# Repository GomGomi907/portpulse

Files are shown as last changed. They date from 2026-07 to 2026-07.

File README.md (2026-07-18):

# PortPulse

## 무엇인가

PortPulse는 PC와 USB 장치(DUT) 사이에 연결하는 USB 2.0 재연결 동글입니다.

PC와 제어 MCU의 연결은 유지한 채, 외부 DUT의 VBUS와 D+/D−를 소프트웨어로
차단하고 복구합니다. 따라서 USB 장치를 실제로 뽑았다가 다시 연결하는 동작을
자동화 테스트에서 재현할 수 있습니다.

## 사용 방법

1. PortPulse의 USB-C upstream 포트를 PC에 연결합니다.
2. DUT를 PortPulse의 USB-A downstream 포트에 연결합니다.
3. 장치 관리자에서 PortPulse의 COM 포트 번호를 확인합니다.
4. 네이티브 `portpulse` 프로그램으로 명령을 보냅니다.

```text
portpulse --port COM12 status
portpulse --port COM12 on
portpulse --port COM12 off
portpulse --port COM12 --delay-ms 2000 cycle
```

주요 명령:

- `on`: DUT 연결
- `off`: DUT 차단
- `cycle`: DUT를 차단한 뒤 지정한 시간 후 다시 연결
- `status`: 현재 상태 확인
- `fault`: 전원 스위치 Fault 상태 확인
- `version`: 펌웨어 버전 확인

현재 Rev.C.1은 DUT 1포트를 지원합니다. 여러 PortPulse를 연결하는 경우에는
각 장치의 COM 포트를 지정해서 사용합니다.

하드웨어·펌웨어·호스트 프로그램은 MIT License로 배포합니다. 제3자 구성요소는
각 구성요소의 고지 파일을 따릅니다.

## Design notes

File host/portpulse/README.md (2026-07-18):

# PortPulse native host

Small native C host for the PortPulse CH552 CDC interface. It uses the OS
serial driver already provided by Windows or Linux; no Python runtime is
required.

Build with CMake:

```sh
cmake -S . -B build
cmake --build build --config Release
```

Examples:

```text
portpulse --port COM12 status
portpulse --port COM12 on
portpulse --port COM12 off
portpulse --port COM12 --delay-ms 2000 cycle
```

The current Rev.C.1 firmware exposes one logical target port. Device
auto-discovery and `--device <serial>` selection are planned for the next
host iteration; explicit port selection is intentional until multi-device
enumeration is added.

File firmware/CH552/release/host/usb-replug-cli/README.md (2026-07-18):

# USB Replug Dongle Rev.C.1 Host CLI

CDC serial CLI for CH552 firmware `0.2.1-revc1`.

## Usage

Run from this directory:

```powershell
py -m usb_replug ports
py -m usb_replug status
py -m usb_replug off
py -m usb_replug on
py -m usb_replug cycle --delay-ms 2000
py -m usb_replug --port COM12 status
py -m usb_replug --port COM12 off
py -m usb_replug --port COM12 on
py -m usb_replug --port COM12 cycle --delay-ms 2000
py -m usb_replug --port COM12 fault
py -m usb_replug --port COM12 version
```

When `--port` is omitted, the CLI auto-discovers a pyserial port matching USB
VID/PID `0x1a86:0x5722`. Override the IDs with decimal or `0x` hex values, and
use `--serial` to require a serial-number substring:

```powershell
py -m usb_replug --vid 0x1A86 --pid 0x5722 ports
py -m usb_replug --serial ABC123 status
```

Auto-discovery fails clearly if no port or more than one port matches. Passing
`--port` always takes precedence over auto-discovery.

The CLI requires `pyserial` when talking to real hardware:

```powershell
py -m pip install pyserial
```

The firmware command protocol uses plain ASCII lines and returns one response line per command.

The CLI rejects `cycle --delay-ms` values outside the firmware
`0.2.1-revc1` range of 100 to 30000 ms before opening the serial port.
For every `cycle`, the serial timeout is raised automatically to at least the
effective delay plus 2 seconds; a cycle without `--delay-ms` uses the firmware
default of 2000 ms. Device `ERR ...` responses are written to stderr and return
exit status 1.

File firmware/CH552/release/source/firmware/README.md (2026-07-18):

# USB Replug Dongle Rev.C.1 — CH552 firmware

This is the production-board firmware target for the cost-optimized Rev.C.1
hardware. The earlier `firmware/usb_replug_fw` directory is the superseded
STM32F042 Rev.C scaffold and must not be flashed to Rev.C.1.

## Implemented behavior

- CH552 USB Full-Speed CDC ACM command interface
- Windows inbox `usbser.sys` compatible device-class descriptors
- Stable chip-ID-derived serial number: `RVC1-XXXXXXXXXX`
- Reset-safe DUT state: VBUS off and D+/D- disconnected
- Active-low Rev.C.1 GPIO mapping
- Fault interlock and automatic safe-off after a fault on power-up
- Commands:
  - `on` / `on 1`
  - `off` / `off 1`
  - `cycle [100..30000]`
  - `cycle 1 [100..30000]`
  - `status [1]`
  - `fault`
  - `version`
  - `help`

The ON sequence connects D+/D- first, waits 20 ms, enables DUT VBUS, waits
100 ms, then checks the over-current fault again. OFF disconnects D+/D-
before removing VBUS.

## Pin contract

| CH552 pin | Net | Logical behavior |
|---|---|---|
| P1.0 / pin 7 | `TARGET_PWR_EN_N` | Low = DUT VBUS on |
| P1.1 / pin 8 | `TARGET_DATA_CMD` | Low = connected; open-drain release = disconnected |
| P3.1 / pin 9 | NC | High-impedance after startup; no CH334U reset connection |
| P3.0 / pin 10 | `TARGET_FAULT_N` | 5 V-domain input; low = over-current fault |
| P3.6 / pin 14 | `MCU_USB_DP` | USB D+ |
| P3.7 / pin 15 | `MCU_USB_DM` | USB D- |

CH334U `RESET#/CDP` is deliberately not driven by the MCU. The hub uses its
internal POR and pull-up as WCH recommends; TP8 remains available to assert a
manual active-low reset during bring-up.

Rev.C.1 powers CH552 `VCC` from `VBUS_IN` (nominal 5 V). That is a mandatory
precondition for the selected 24 MHz system clock; the build fails if
`CH552_VCC_MV` is configured below 4400.

## Build and tests

Prerequisites:

- SDCC 4.6.0 with MCS-51 support
- Python 3
- GCC for portable host-side C tests

Run:

```powershell
cd D:\oh_my_usb\firmware\usb_replug_ch552
py build.py all
```

Outputs:

```text
build/sdcc/usb_replug_ch552.bin
build/sdcc/usb_replug_ch552.hex
build/sdcc/usb_replug_ch552.ihx
build/sdcc/usb_replug_ch552.map
build/sdcc/usb_replug_ch552.mem
```

The build enforces the CH552 application limits: code below `0x3800` because
the upper 2 KiB is the factory bootloader, and application XRAM from `0x0100`
through `0x03ff`. USB DMA buffers occupy the hardware-sized fixed regions
`0x0000..0x003f` (EP0), `0x0040..0x007f` (EP1 TX), and
`0x0080..0x00ff` (EP2 RX/TX).

The build script also works around an SDCC 4.6.0 Windows packaging issue where
the private preprocessor backend can otherwise be confused with MinGW's
`cc1.exe`.

## USB identifiers

The default engineering VID/PID is `1A86:5722`, matching the host CLI defaults.
It is not an ownership grant. Before distribution, replace it at build time
with manufacturer-owned or licensed identifiers:

```powershell
# Add -DUSB_REPLUG_VID=... and -DUSB_REPLUG_PID=... to the SDCC flags.
```

## Programming

J3 exposes VBUS, GND, RST, P1.4, P1.6, and P1.7 for CH552 ISP/programming.
Program `build/sdcc/usb_replug_ch552.bin` with a CH55x-compatible WCH ISP tool.
Do not erase or overwrite the factory bootloader region at `0x3800..0x3fff`.

## Physical validation still required

Offline tests validate the command state machine, GPIO ordering contract,
descriptor structure, toolchain link, and memory limits. Final acceptance
requires assembled hardware for USB enumeration, voltage-level checks, fault
injection, and repeated DUT replug testing.

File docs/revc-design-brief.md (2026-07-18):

# USB Replug Dongle Rev.C — USB-stick-class redesign brief

Date: 2026-06-23

## Decision

Skip Rev.B and target Rev.C directly as a compact USB-stick-class product spin.

## Rev.C target

- Functional scope: keep Rev.A core function unchanged: PC sees a USB 2.0 hub, always-connected control MCU, and switched target USB port.
- Mechanical target: 55–62 mm length × 18–22 mm width.
- First layout envelope: 62 mm × 22 mm if retaining the current USB-A female footprint; shrink toward 55 mm × 20 mm after connector/MCU package selection.
- PCB: 4-layer FR-4, continuous inner GND reference for USB 2.0 HS.
- Assembly: JLCPCB full PCBA, top-side-first; bottom-side passives/debug pads allowed only if top-side placement cannot meet the envelope.
- Routing priority: USB HS, crystal, VBUS trunk/switch, 3V3 decoupling, then low-speed GPIO/LED/debug.

## Connector architecture

Primary Rev.C mechanical architecture:

- Upstream: USB-C plug or compact USB-C upstream connector variant, USB 2.0-only UFP/Sink behavior.
- Downstream: USB-A female for DUT compatibility.

Mechanical fallback if JLC sourcing/assembly of a USB-C plug is poor:

- Keep a compact USB-C receptacle for Rev.C-P0 fit validation.
- Preserve the same electronics and layout zones so the upstream connector can be swapped after part availability is confirmed.

Rationale:

- Current Rev.A pad survey shows the USB-A female is the dominant size limiter.
- Current J2 pad box is about 14.0 mm × 9.42 mm; including body/courtyard it drives a realistic 18–22 mm board width.
- USB-stick-class is therefore realistic without changing the downstream connector, but aggressive 17–18 mm widths require connector-specific keepout checking.

## Component/package strategy

| Block | Rev.A state | Rev.C direction |
|---|---|---|
| USB hub | USB2422 QFN 4×4 | Keep if JLC availability/assembly is acceptable; already compact |
| MCU | STM32F042 TSSOP-20 | Prefer QFN/UFQFPN STM32F042 variant or equivalent USB-FS MCU; keep firmware model |
| Data switch | TS3USB30E VSSOP-10 | Keep or migrate to same-function smaller package only if JLC-safe |
| VBUS switch | TPS2553 SOT-23-6 | Keep unless part availability/cost drives replacement |
| LDO | AP2112K SOT-23-5 | Keep or smaller compatible LDO if stock favors it |
| ESD | SOT-23-6 USB ESD | Prefer lower-profile low-capacitance arrays near connectors |
| Passives | 0603 | Move to 0402 for Rev.C density, except current-limit/USB tuning pads where hand-rework is useful |
| Debug | Tag-Connect + buttons | Replace with tiny pogo/SWD pads; remove large reset button; boot via pad/jumper |
| LEDs | 3 LEDs | Reduce to 1–2 LEDs or edge-visible 0402 LEDs |

## Placement zoning

Left-to-right signal flow for the compact layout:

1. Upstream USB connector / plug
2. Upstream ESD and CC/Rd network
3. USB hub + 24 MHz crystal adjacent
4. MCU in parallel branch off hub port 1
5. Data switch and downstream ESD near downstream connector
6. VBUS switch near downstream connector power pin
7. USB-A downstream at board end

Keep USB HS traces short, symmetric, and over unbroken GND. Do not let the auto-router route USB, crystal, or switched VBUS before those classes are manually/fixed routed.

## JLCPCB constraints to preserve

- 0402 is within JLCPCB assembly capability, but use order-time preview and part selection.
- BOM and CPL must keep exact refdes matching.
- Through-hole/mechanical connector pads must be explicitly accepted by JLC engineering preview if used.
- Current Rev.A 0.30/0.15 mm vias are manufacturable-edge; Rev.C should prefer larger vias where possible, e.g. 0.45/0.20 mm, unless density forces smaller.
- Controlled-impedance dimensions must be selected from the actual JLC stack-up/impedance calculator before release.

Sources checked during planning:

- JLCPCB PCB Assembly Capabilities: https://jlcpcb.com/capabilities/pcb-assembly-capabilities
- JLCPCB PCB Capabilities: https://jlcpcb.com/capabilities/pcb-capabilities
- JLCPCB PCB Assembly FAQs: https://jlcpcb.com/help/article/pcb-assembly-faqs
- JLCPCB PCB Assembly FAQs Part 2: https://jlcpcb.com/help/article/pcb-assembly-faqs-part-2
- JLCPCB via design best practices: https://jlcpcb.com/blog/pcb-via-design-best-practices

## Phase gates

### Rev.C Phase 0 — package and mechanical lock

Exit gate:

- Target connector footprints chosen.
- Board outline target fixed.
- All assembled parts have JLC/LCSC candidates or explicit order-time sourcing notes.
- USB stick envelope drawing/placement keepouts saved.

### Rev.C Phase 1 — schematic/BOM

Exit gate:

- ERC 0 or documented waivers.
- Package substitutions reflected in symbol pin mapping and footprints.
- JLC BOM metadata complete for assembled parts.

### Rev.C Phase 2 — compact PCB

Exit gate:

- DRC 0, unconnected 0, schematic parity 0.
- Route quality audit passes hard checks.
- Soft warnings are documented and tied to Rev.C risk log.

### Rev.C Phase 3 — manufacturing release

Exit gate:

- Fresh ERC/DRC immediately before export.
- Gerber/drill/BOM/CPL package audit PASS.
- Release notes explicitly call out connector through-hole/mechanical soldering, polarity, rotations, stock, and impedance settings.

## Immediate next implementation step

Create `USB_Replug_Dongle_RevC` as a separate KiCad project so Rev.A manufacturing files remain frozen. Start with a compact placement feasibility board, then replace high-impact packages/footprints before routing.

## Rev.C P1 — 55×20mm USB-stick feasibility update

Date: 2026-06-23

P1 now proves a 55.0 mm × 20.0 mm USB-stick-class placement envelope using the Rev.A electrical architecture with Rev.C package reductions:

- 0402-class R/C/LED footprints.
- compact SWD pogo pads instead of Tag-Connect.
- compact reset/boot solder/tweezer pads instead of a tact reset switch.
- 0.7 mm compact test pads.

Verification:

- Placement audit: `.omx/reports/revc-usb-stick-p1-placement-20260623.json`
  - pads outside outline: 0
  - body outside outline, excluding the upstream connector placeholder policy: 0
  - bounding-box overlaps: 0
  - unplaced/fallback refs: 0
- ERC: `.omx/reports/revc-p1-erc-20260623.rpt`, 0 errors / 0 warnings
- Visual export: `.omx/reports/revc-usb-stick-p1-placement-20260623.pdf`

P1 is not order-ready: routing is intentionally removed, and the 0402 passive LCSC BOM must be re-locked because Rev.A C-numbers such as `C19702` and `C14663` are 0603 examples.

Rev.C P1 BOM risk audit added: .omx/reports/revc-p1-bom-package-risk-20260623.md flags 54 inherited Rev.A passive/debug package-code rows that must be re-locked for 0402 before manufacturing release.

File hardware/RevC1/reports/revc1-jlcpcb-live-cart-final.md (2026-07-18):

# Rev.C.1 JLCPCB Live Cart Final Verification

- Date: 2026-07-18 (Asia/Seoul)
- Verdict: **PASS**
- Scope: 5 PCB + 5 fully assembled PCBA, 4-layer Economic, top-side assembly
- Safety boundary: checkout/payment was not entered or performed

## Uploaded Rev.C.1 production files

| File | SHA-256 |
| --- | --- |
| `USB_Replug_Dongle_RevC1_JLCPCB_OrderReady_20260718_gerber_drill.zip` | `6CAC9D513B0341766E7C2989DBD89D8055B379E69DD07F3453C60F4855EF2A31` |
| `assembly/bom.csv` | `A1331FF0323D9E58D634FFF232963443D5E3F201F3BE2198E1995F59E3411CD3` |
| `assembly/positions.csv` | `DFCEBD58D2873A6FD562ABC5523707EB8AB6C0F7B3BF3549781511A473CA3BE5` |

The live Gerber parser detected a 4-layer board measuring 21.6 × 49.5 mm, equivalent to the source 49.5 × 21.6 mm orientation.

## Live configuration

- PCB quantity: 5
- PCBA quantity: 5
- PCB layers: 4
- Assembly service: Economic
- Assembly side: Top Side
- Fully assembled PCBA: enabled
- Engineer placement review: enabled
- Automatic placement confirmation: disabled
- Assembly terms: accepted
- Economic-mode nitrogen reflow: `Yes (for Economic)`; the UI disabled `No`
- PCBA remark: saved; its charge remains `Quote after review`
- Customs description: `Reserch\Education\DIY\Entertainment / Development Board - HS Code 847330`

## Live BOM match and availability

All 14 BOM rows were selected with the exact requested LCSC part number and a positive procurement quantity.

| References | Exact LCSC | Procurement quantity | Live result |
| --- | --- | ---: | --- |
| C1, C10 | C19702 | 10 | Selected |
| C2, C3 | C15849 | 10 | Selected |
| C4-C9 | C14663 | 30 | Selected |
| J1 | C7507405 | 5 | Selected |
| J2 | C8328 | 6 | Selected; JLCPCB stock 13,558 and idle stock 409 |
| R1, R2, R4-R9 | C23186 | 40 | Selected |
| R10 | C107231 | 20 | Selected |
| U1 | C5187524 | 5 | Selected |
| U2 | C111367 | 5 | Selected |
| U3 | C11355 | 5 | Selected |
| U4 | C46506 | 5 | Selected |
| U5 | C5446 | 5 | Selected |
| U6, U7 | C7519 | 12 | Selected |
| Y1 | C9002 | 5 | Selected |

J2 was explicitly selected as exact part `C8328`; no substitute was used. The current live order and final cart contain none of the stale/forbidden identifiers `C25744`, `C25804`, `C4154405`, or `CH334R`.

## Placement and rotation verification

- 29/29 placements are mounted, on layer `T`, and mapped to the exact intended LCSC ID.
- After JLCPCB auto-alignment, the global coordinate transform was consistent: X was preserved for 28/29 placements; J1 alone had a -0.125 mm X model-anchor offset. All 29 Y coordinates followed the JLCPCB sign-inverted coordinate frame.
- Key final rotations: J1 270°, J2 90°, U1 90°, U2 270°, U3 270°, U4 0°, U5 180°, U6 270°, U7 270°, Y1 0°.
- The corrected 2D and 3D previews place J1 opening left toward the PC and J2 opening right toward the DUT. IC/connector pin-1 and orientation markers align with their footprints.
- J1/J2 mixed SMT/PTH shell pads and models were accepted by the placement editor.

## Exact live quote breakdown

### PCB

| Line | Price |
| --- | ---: |
| PCB Price | $2.00 |
| Via Covering | $0.00 |
| Confirm Production file | $0.00 |
| PCB build time, 3 days | $0.00 |
| **PCB subtotal** | **$2.00** |

The final cart shows a struck reference PCB price of $7.00 and a Special offer price of $2.00, an exact displayed discount of **$5.00**.

### Economic PCBA

| Line | Price |
| --- | ---: |
| Setup Fee | $8.18 |
| Stencil | $1.53 |
| Panel | $0.00 |
| Large Size | $0.00 |
| Components, 14 items | $16.09 |
| Extended components fee | $24.56 |
| SMT Assembly | $1.22 |
| Confirm Parts Placement | $0.45 |
| Special components fee | $0.18 |
| Nitrogen reflow soldering | $0.90 |
| Assembly lead time, 3-4 days | $0.00 |
| **Economic PCBA subtotal** | **$53.11** |

The priced PCBA lines sum exactly to $53.11. The PCBA remark is shown as `Quote after review` and is not included in the total.

### Total and shipping

- **Order quote total before shipping: $55.11**
- Calculated weight: 291.90 g
- Shipping Estimated: `--`
- Final unchecked-cart Merchandise Total: `$0.00`
- Final unchecked-cart Subtotal: `$0.00`

Shipping is not quoted while every cart checkbox remains unselected. No checkbox was selected merely to obtain a shipping price, and checkout was not entered.

## Final cart integrity

- Cart count: `All (1)` / `JLCPCB (1)`
- Exactly one cart group contains one linked PCB+PCBA pair:
  - PCB: `PCB prototype:Y6-9897851A`, quantity 5, $2.00
  - PCBA: `Economic PCBA: SMT026071860674-9897851A`, top-side, quantity 5, $53.11
- Both entries share link suffix `9897851A`.
- All three visible cart checkboxes were programmatically verified `checked=false`.
- No Secure Checkout, checkout, payment, or order submission action was performed.

## Evidence

- `browser-evidence/03-placement-auto-aligned.png`
- `browser-evidence/04-placement-2d-top.png`
- `browser-evidence/05-final-cart-unchecked.png`

## Final verdict

**PASS** — The new Rev.C.1 Gerber/BOM/CPL set is the sole current linked PCB+PCBA cart pair; the stale C25744 condition is absent; all exact BOM parts have live positive availability; placement/orientation is aligned; quantities and requested manufacturing settings are correct; and the final cart is fully unchecked with no checkout or payment.

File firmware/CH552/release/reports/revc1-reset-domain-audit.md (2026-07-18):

# Rev.C.1 Reset-Domain Audit

- Verdict: PASS
- FSUSB /OE POR maximum: 2.6513 V (< 3.3 V)
- FSUSB /OE released minimum: 1.5623 V (> 1.3 V)
- CH334U RESET#/CDP: only U1.17 + TP8; CH552 P3.1 is NC.
- TPS2552 FAULT: U4.4 + U2.10 + TP7 with R7 pull-up to VBUS_IN.

## Checks

- [x] hub_reset_only_u1_and_tp8
- [x] ch552_p3_1_is_unconnected
- [x] fault_net_exact_members
- [x] fault_pullup_is_5v
- [x] fault_not_tied_to_3v3
- [x] oe_upper_pullup_is_5v
- [x] oe_series_path
- [x] oe_resistors_are_equal_5k1
- [x] oe_por_below_3v3
- [x] oe_release_above_vih_min

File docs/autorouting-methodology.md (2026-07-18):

# Professional Autorouting Methodology — USB Replug Dongle Rev.A

## Purpose

This document defines how this KiCad project should evolve from connectivity-only autorouting to evidence-based, manufacturable, reviewable routing. It is the source-of-truth methodology for later scripts and routing-intent files.

Baseline project evidence:
- Board: `USB_Replug_Dongle_RevA/USB_Replug_Dongle_RevA.kicad_pcb`
- Baseline metrics: `.omx/reports/autorouting-ultragoal-g001-baseline.json`
- Prior research: `.omx/reports/deep-research-autorouting-rules-20260622.md`

## Evidence Hierarchy

1. **Hard manufacturing limits**: selected JLCPCB stack-up/copper/capability limits. JLCPCB tells users to set KiCad rules for minimum track width, spacing, via sizes, drill diameters, and other critical parameters before manufacturing export and to rerun DRC. Source: <https://jlcpcb.com/help/article/how-to-generate-gerber-and-drill-files-in-kicad-9>
2. **High-speed electrical rules**: USB 2.0 DP/DM route impedance, symmetry, continuous plane, via/corner minimization. Microchip states USB 2.0 DP/DM should maintain nominal 90 ohm differential impedance and that width/spacing must be recalculated for dielectric thickness/copper/stack-up. Source: <https://ww1.microchip.com/downloads/en/AppNotes/AN13.10-Application-Note-DS00002972A.pdf>
3. **Component-specific layout rules**: TI TS3USB30E requires equal-length D+/D-, impedance match, minimum vias/corners, careful via clearance, avoidance of through-hole test points on twisted pair lines, avoidance near clocks/crystals/regulators, and continuous planes. Source: <https://www.ti.com/lit/gpn/TS3USB30E>
4. **KiCad executable constraints**: net classes, custom rules, diff-pair gap/skew/length/uncoupled constraints, and DRC are the final machine-verifiable contract. Source: <https://docs.kicad.org/9.0/en/pcbnew/pcbnew.html>
5. **External autorouter limits**: Freerouting consumes DSN/SES and has net class/via/clearance/length concepts, but it does not inherently know datasheet intent unless encoded in rules, placement, fixed tracks, or postprocessing. Sources: <https://github.com/freerouting/freerouting>, <https://freerouting.org/freerouting/manual/routing-options>

## Routing Intent Model

Every net belongs to exactly one semantic class. A class compiles to KiCad net class/custom rules, Freerouting rules where possible, and local scoring rules.

| Class | Examples | Hard constraints | Soft cost priorities |
|---|---|---|---|
| `usb2_hs_pair` | `/USB_UP_DP_RAW` + `/USB_UP_DM_RAW`, hub-switch-DUT pairs | JLC-derived width/gap for 90 ohm differential, continuous reference plane, no clock/crystal/regulator keepout violation, DRC clean | fewest vias, shortest route, pair symmetry, low skew, low uncoupled length, native arc or two-45 corners |
| `usb_fs_internal` | MCU USB downstream control path | width/clearance, DRC clean, ESD/connector proximity if exposed | short path, few bends, avoid noisy areas |
| `vbus_power` | `/VBUS_IN`, `/VBUS_DUT_SW`, `/VBUS_DUT` | min width from current/temperature policy, no neckdown below policy, switch topology order | short/wide trunk, minimal via bottlenecks, large clearance margin |
| `logic_power` | `/3V3` | DRC clean, decoupling connectivity | short cap fanout, low via count, plane use |
| `crystal_clock` | `/HUB_XTALIN`, `/HUB_XTALOUT` | short local routing, keep USB away from crystal region | compact symmetry, low loop area |
| `control_gpio` | EN/OE/FAULT/LED/reset/strap | DRC clean, reset/strap deterministic pull state | route after critical nets, low visual clutter |
| `ground` | `/GND` | continuous reference plane and GND stitching where needed | preserve unbroken plane under USB |

## Router Pipeline

1. **Preflight**
   - Load board and schematic artifacts.
   - Confirm selected JLC stack-up and KiCad board constraints.
   - Confirm existing baseline DRC/ERC evidence or rerun when generating release changes.

2. **Placement locks**
   - Lock connectors, hub, USB data switch, ESD, power switch, crystal, and debug header before routing experiments.
   - Keep ESD close to exposed connector paths and keep crystal local.

3. **Critical-net routing first**
   - Route USB pairs before low-speed nets.
   - Route VBUS/power trunks before GPIO.
   - Route crystal/clock locally and protect it with USB keepout.

4. **External completion**
   - Export DSN only after critical nets are fixed or scored.
   - Use Freerouting for low-risk remaining nets.
   - Import SES and immediately run route audit + DRC.

5. **Post-route beautification**
   - Apply native arcs/fillets only after routing is stable.
   - Keep an editable source board and generate rounded output/copy.
   - KiCad warns that tracks with arcs are immovable by the shove router, so arc conversion is a finalization step rather than an early routing primitive. Source: <https://docs.kicad.org/9.0/en/pcbnew/pcbnew.html>

6. **Verification gates**
   - KiCad DRC: 0 violations, 0 unconnected pads, 0 footprint errors unless explicitly waived.
   - Route audit: score does not regress for critical nets; USB pair skew/uncoupled/via count within configured limits.
   - Manufacturing audit: JLC constraints remain compatible with selected process.

## Scoring Model

The scoring model intentionally separates **hard fail** from **soft quality**.

### Hard Fail

A route fails if any of these are true:
- KiCad DRC reports unwaived violations.
- A critical net is unrouted or disconnected.
- A USB pair violates configured diff-pair width/gap/skew/uncoupled/via-count constraints.
- A USB route crosses a configured keepout near crystal/clock/switching-regulator regions.
- A power route has a segment narrower than configured current policy.

### Soft Score

Lower score is better:

```text
score =
  1.0 * total_length_mm
+ 8.0 * via_count
+ 5.0 * layer_change_count
+ 1.5 * corner_count
+ 4.0 * non_45_or_arc_corner_count
+ 0.5 * small_segment_count
+ 10.0 * usb_pair_skew_mm
+ 6.0 * usb_pair_uncoupled_mm
- 2.0 * clearance_margin_bonus
- 3.0 * preferred_layer_bonus
- 2.0 * native_arc_corner_bonus
```

Weights are starting values for this project. They should be calibrated by comparing baseline board metrics and DRC-clean alternatives.

## Arc/Rounded Corner Policy

| Net class | Policy |
|---|---|
| `usb2_hs_pair` | Prefer native arcs after routing; fallback to two 45-degree turns. TI explicitly allows two 45-degree turns or an arc instead of a single 90-degree turn for USB high-speed signals. Source: <https://www.ti.com/lit/gpn/TS3USB30E> |
| `vbus_power` | Use chamfer/arc only if it does not reduce width or create clearance/thermal bottleneck. |
| `control_gpio` | Use 45-degree or arc by aesthetic score; never sacrifice critical-net clearance. |

## Deterministic Artifacts

The methodology compiles into:

- `routing/routing_sources.yaml` — cited source rules and extraction notes.
- `routing/routing_intent.yaml` — net classes, pair definitions, width/gap/via/skew/corner policies.
- `tools/route_quality_audit.py` — metric and scoring tool.
- `.omx/reports/autorouting-route-quality-current.json` — current board metrics.
- `.omx/reports/autorouting-route-quality-current.md` — human review report.

## Non-goals for This Ultragoal

- Do not place JLCPCB orders or claim live order validation.
- Do not mutate the verified production board without a copy and fresh DRC evidence.
- Do not claim actual 90 ohm performance until a selected JLC stack-up is used to calculate and review width/gap.

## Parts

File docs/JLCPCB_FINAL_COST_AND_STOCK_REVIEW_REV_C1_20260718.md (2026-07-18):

# USB Replug Dongle Rev.C.1 — Final JLCPCB Cost/Stock Review

Date: 2026-07-18  
Order target: 5 PCBs / 5 fully assembled top-side PCBAs  
Board: 4-layer, 49.5 mm × 21.6 mm

## Final design decisions

- Use CH334U `C5187524` in QSOP-28 instead of CH334R `C4154405`.
  The logged-in JLCPCB review showed only 2 assembly-stock units for CH334R,
  which cannot satisfy a five-PCBA order. CH334U showed 1,101 units and avoids
  QFN X-ray cost.
- Replace the unavailable 10 kΩ `C25804` group with the already-used Basic
  5.1 kΩ `C23186`. R1/R2/R4-R9 now share one line item. The equal R6/R8/R9
  ratio preserves the reset-safe FSUSB42 `/OE` limits.
- Keep USB-C upstream `C7507405` and USB-A female downstream `C8328`.
  The latter showed 13,558 units during the logged-in review. Both exact
  footprints and mating directions are verified in the connector audit.
- Keep all five PCBAs assembled. Setup, stencil, and regular-Extended feeder
  charges are order-level costs; leaving one board bare does not materially
  reduce them and removes one usable/debug unit.
- Keep four layers. The PCB remains under the 50 mm promotion boundary while
  preserving an uninterrupted In1.Cu GND reference under USB 2.0 HS paths.

## BOM cost structure

Regular Extended types are limited to seven:

1. J1 USB-C connector
2. J2 USB-A connector
3. U1 CH334U hub
4. U2 CH552T MCU
5. U3 FSUSB42MUX
6. U4 TPS2552 power switch
7. U6/U7 USBLC6-2SC6 ESD array

Basic parts cover the LDO, crystal, all capacitors, and all resistors. The
final BOM has 14 rows and 29 fitted references; BOM and CPL reference sets are
identical and all placements are top side.

## Quote options

- Economic PCBA, top side only
- Quantity 5 PCB / 5 PCBA
- Disable optional nitrogen reflow unless JLCPCB requires it
- Keep engineer placement review enabled
- Do not select X-ray or double-sided assembly unless the UI requires it
- Confirm connector mixed SMT/PTH shell-pad processing in the engineering
  preview

## Live order gate

Stock and pricing are time-sensitive. Immediately before cart save/payment:

1. Re-check every LCSC row and reject any automatic substitution that changes
   electrical rating, pinout, package, or connector geometry.
2. Confirm U1 is `C5187524`, the 5.1 kΩ group is `C23186`, J1 is `C7507405`,
   and J2 is `C8328`.
3. Confirm no obsolete `C25744`, unavailable `C25804`, or short-stock
   `C4154405` is selected.
4. Verify exactly one linked PCB/PCBA pair exists in the cart and all checkout
   checkboxes remain clear.
5. Record the final PCB, assembly, components, Extended feeder, special
   component, review, optional-process, shipping, and total amounts.

Payment/checkout is outside this release gate and requires the user.

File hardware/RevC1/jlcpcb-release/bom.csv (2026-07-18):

Designator | Footprint | Quantity | Value | LCSC Part # | MPN | Manufacturer | Assembly Notes
C1,C10 | Capacitor_SMD:C_0603_1608Metric | 2 | 10uF 10V X5R | C19702 | 10uF 10V X5R | Generic | Top SMT; JLCPCB Economic PCBA
C2,C3 | Capacitor_SMD:C_0603_1608Metric | 2 | 1uF 16V X5R | C15849 | 1uF 16V X5R | Generic | Top SMT; JLCPCB Economic PCBA
C4,C5,C6,C7,C8,C9 | Capacitor_SMD:C_0603_1608Metric | 6 | 100nF 16V X7R | C14663 | 100nF 16V X7R | Generic | Top SMT; JLCPCB Economic PCBA
J1 | USB_Replug_Dongle_RevC1:C7507405_USB_C | 1 | TYPE-C-3.1-16PIN | C7507405 | TYPE-C-3.1-16PIN | SHOU HAN | Top SMT/PTH shell; opening at left edge
J2 | USB_Replug_Dongle_RevC1:C8328_USB_A | 1 | 904-131A2032S10100 | C8328 | 904-131A2032S10100 | Jing Extension of the Electronic Co. | Top SMT/PTH locating holes; opening at right edge
R1,R2,R4,R5,R6,R7,R8,R9 | Resistor_SMD:R_0603_1608Metric | 8 | 5.1k 1% | C23186 | 5.1k 1% | Generic | Top SMT; JLCPCB Economic PCBA
R10 | Resistor_SMD:R_0603_1608Metric | 1 | 51k 1% | C107231 | 51k 1% | Generic | Top SMT; JLCPCB Economic PCBA
U1 | Package_SO:QSOP-28_3.9x9.9mm_P0.635mm | 1 | CH334U | C5187524 | CH334U | WCH | Top SMT; JLCPCB Economic PCBA
U2 | Package_SO:TSSOP-20_4.4x6.5mm_P0.65mm | 1 | CH552T | C111367 | CH552T | WCH | Top SMT; JLCPCB Economic PCBA
U3 | Package_SO:MSOP-10_3x3mm_P0.5mm | 1 | FSUSB42MUX | C11355 | FSUSB42MUX | onsemi | Top SMT; JLCPCB Economic PCBA
U4 | Package_TO_SOT_SMD:SOT-23-6 | 1 | TPS2552DBVR | C46506 | TPS2552DBVR | Texas Instruments | Top SMT; JLCPCB Economic PCBA
U5 | Package_TO_SOT_SMD:SOT-23 | 1 | XC6206P332MR-G | C5446 | XC6206P332MR-G | Torex | Top SMT; JLCPCB Economic PCBA
U6,U7 | Package_TO_SOT_SMD:SOT-23-6 | 2 | USBLC6-2SC6 | C7519 | USBLC6-2SC6 | STMicroelectronics | Top SMT; JLCPCB Economic PCBA
Y1 | Crystal:Crystal_SMD_3225-4Pin_3.2x2.5mm | 1 | 12 MHz | C9002 | X322512MSB4SI | YXC | Top SMT; JLCPCB Economic PCBA

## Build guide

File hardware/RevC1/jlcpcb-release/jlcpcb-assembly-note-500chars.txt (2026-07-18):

4-layer FR-4; top-side full assembly. Enable engineer review. J1 USB-C opens LEFT/PC; J2 USB-A opens RIGHT/DUT. Verify J1/J2 mixed SMT/PTH shell pads, U1-U7 pin-1/orientation, U6/U7 ESD direction, and Y1 before assembly.

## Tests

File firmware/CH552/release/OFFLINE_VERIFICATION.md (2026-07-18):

# Rev.C.1 firmware offline verification

Date: 2026-07-18  
Verdict: **PASS**

## Evidence

- Portable C tests: 3/3 PASS
- GPIO safety tests: 2/2 PASS
- Python host CLI tests: 16/16 PASS
- Clean SDCC builds: 2/2 PASS and byte-for-byte reproducible
- Code: 5897 / 14336 bytes
- Application XRAM: 79 / 768 bytes
- USB DMA: EP0 `0x0000`, EP1 `0x0040`, EP2 `0x0080`
- Highest image address: `0x1708`, below bootloader boundary `0x3800`
- IHX/HEX checksums valid; BIN matches Intel HEX
- Reset-domain schematic audit: PASS

The exact logs and reproducibility hashes are included under `reports/`.

## Hardware acceptance still required

- Inspect connector/IC orientation and assembly quality
- Measure VBUS_IN, 3V3, TARGET_DATA_OE_N, TARGET_FAULT_N, and DUT VBUS
- Verify safe-off before and during MCU programming/reset
- Verify CH334U hub and CH552 CDC enumeration on Windows/Linux/macOS
- Exercise `on`, `off`, `cycle`, `status`, `fault`, and `version`
- Inject TPS2552 over-current and verify forced safe-off
- Complete 100 replug cycles for each representative DUT

No offline test can replace these physical checks.

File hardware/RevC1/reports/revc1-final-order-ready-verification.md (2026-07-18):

# USB Replug Dongle Rev.C.1 Final Order-Ready Verification

Date: 2026-07-18 (Asia/Seoul)

## Decision

- Local engineering release: **PASS**
- JLCPCB live stock / quote / cart: **PASS**
- Payment / checkout: **NOT AUTHORIZED**
- JLCPCB order-ready state: **PASS**, left in cart before checkout.

## Hardware verification

- KiCad: 9.0.6
- Board: 49.5 mm x 21.6 mm, 4 layers
- ERC: 0 errors, 0 warnings
- DRC: 0 violations, 0 unconnected pads, 0 footprint errors
- Route audit: PASS, 0 warnings
- Differential-pair gates: all PASS
  - USB_UP_RAW: 1.200 mm skew / 1.500 mm limit, 0/0 vias
  - USB_UP_HUB: 0.750 mm / 1.000 mm, 0/0 vias
  - MCU_USB_FS: 0.661 mm / 2.000 mm, 2/2 vias
  - HUB_DUT: 0.056 mm / 1.000 mm, 0/0 vias
  - DUT_SWITCH: 0.862 mm / 1.000 mm, 0/0 vias
  - DUT_CONNECTOR: 0.042 mm / 1.000 mm, 0/0 vias
- In1.Cu remains the GND reference plane; the long upstream VBUS trunk is on In2.Cu.
- Reset-domain audit: PASS
  - CH552 P3.1 is unconnected.
  - CH334U reset is only U1.17 + TP8.
  - TARGET_FAULT_N is in the 5 V domain and is not tied to 3V3.
  - FSUSB42 /OE divider calculated POR maximum: 2.6513 V, below 3.3 V absolute maximum.
  - Released minimum: 1.5623 V, above 1.3 V VIH minimum.
- Connector orientation audit: PASS
  - J1 USB-C upstream opens left toward the PC.
  - J2 USB-A female downstream opens right toward the DUT.
- High-resolution visual evidence:
  - `.omx/reports/revc1/visuals/top-assembly-inspect-hi.png`
  - `.omx/reports/revc1/visuals/bottom-copper-inspect-hi.png`

## JLCPCB package verification

- Clean-generated release:
  - `production/USB_Replug_Dongle_RevC1_JLCPCB_OrderReady_20260718`
- PCB upload:
  - `production/USB_Replug_Dongle_RevC1_JLCPCB_OrderReady_20260718/USB_Replug_Dongle_RevC1_JLCPCB_OrderReady_20260718_gerber_drill.zip`
- Assembly BOM:
  - `production/USB_Replug_Dongle_RevC1_JLCPCB_OrderReady_20260718/assembly/bom.csv`
- Assembly CPL/POS:
  - `production/USB_Replug_Dongle_RevC1_JLCPCB_OrderReady_20260718/assembly/positions.csv`
- Full release:
  - `production/USB_Replug_Dongle_RevC1_JLCPCB_OrderReady_20260718_FULL_RELEASE.zip`
- Package audit: PASS
  - 16 Gerber/drill files
  - 14 BOM rows
  - 29 BOM references
  - 29 CPL references
  - BOM/CPL reference sets exactly match
  - No blank LCSC IDs
  - Top-side placement only
  - Assembly note: 220 / 500 characters
  - No active `C25744`, `C25804`, `C4154405`, or `CH334R`
- ZIP and manifest audit: PASS
  - Gerber ZIP SHA256: `6CAC9D513B0341766E7C2989DBD89D8055B379E69DD07F3453C60F4855EF2A31`
  - Assembly ZIP SHA256: `FDB6252F8063E1923F6F2B85874C8F09CB350C59847E999AF33D1EB8ECEFE83E`
  - Full release ZIP SHA256: `EB85C8252D5551C67B9F9A2CA2FB962723F9D101DD1DD118982638C981A836F7`
  - No duplicate entries, empty entries, read/CRC errors, missing manifest files, or hash mismatches

## Active assembly parts

- U1: CH334U, `C5187524`
- U2: CH552T, `C111367`
- U3: FSUSB42MUX, `C11355`
- U4: TPS2552DBVR, `C46506`
- U5: XC6206P332MR-G, `C5446`
- U6/U7: USBLC6-2SC6, `C7519`
- J1: USB-C, `C7507405`
- J2: USB-A female, `C8328`
- R1/R2/R4-R9: 5.1 kOhm 1%, `C23186`
- R10: 51 kOhm 1%, `C107231`

The old out-of-stock `C25744` 10 kOhm row is not used. The reset-safe resistor network and USB-C CC resistors are consolidated into stocked 5.1 kOhm `C23186`.

## Firmware and host verification

- Firmware version: `0.2.1-revc1`
- Two clean SDCC builds: byte-for-byte reproducible
- Host C tests: 3 PASS
- GPIO safety tests: 2 PASS
- Python CLI tests: 16 PASS
- Code: 5897 / 14336 bytes
- Application XRAM: 79 / 768 bytes
- Highest image address: 0x1708, below 0x3800
- Firmware ZIP SHA256: `37225ECC2BB1FFBF4918625DBFD60FC98C07447F9D33B51DEC0B4F111A4F7611`
- Firmware release audit: PASS, 34 files, no CRC/duplicate/empty/hash error

## Mandatory live JLCPCB checks

1. Upload only the clean Rev.C.1 Gerber/BOM/CPL listed above.
2. Set 5 PCBs and 5 fully assembled PCBAs.
3. Use 4-layer Economic PCBA, top-side assembly.
4. Confirm every LCSC row is matched and in stock; the interface must contain no `C25744` error.
5. Confirm J1 opens left and J2 opens right in the placement preview.
6. Confirm U1/U2/U3/U4/U5/U6/U7 pin-1/orientation and Y1 orientation.
7. Remove optional nitrogen unless JLCPCB requires it; retain engineering placement review.
8. Leave exactly one current PCB + PCBA linked pair in the cart.
9. Leave every cart checkbox unselected.
10. Do not proceed to checkout or payment.

All ten live checks passed on 2026-07-18. Detailed evidence:

- `.omx/reports/revc1/revc1-jlcpcb-live-cart-final.md`
- `.omx/reports/revc1/browser-evidence/03-placement-auto-aligned.png`
- `.omx/reports/revc1/browser-evidence/04-placement-2d-top.png`
- `.omx/reports/revc1/browser-evidence/05-final-cart-unchecked.png`

Live order state:

- Exact linked PCB/PCBA suffix: `9897851A`
- PCB quantity: 5
- Fully assembled Economic top-side PCBA quantity: 5
- Cart groups: 1
- Visible cart checkboxes: 3, all unchecked
- PCB subtotal: $2.00
- PCBA subtotal: $53.11
- Total before shipping: $55.11
- Shipping: not calculated because the cart remains unchecked
- Checkout/payment: not performed
- `C25744`, `C25804`, `C4154405`, and `CH334R`: absent
- J2 `C8328`: exact part selected manually; live JLCPCB stock 13,558, idle stock 409

## Remaining post-receipt gate

No software-only review can replace physical bring-up. After assembly, verify rails, current limit/fault behavior, hub + MCU USB enumeration, DUT disconnect/reconnect behavior, and the 100-cycle test matrix before treating the design as field-qualified.

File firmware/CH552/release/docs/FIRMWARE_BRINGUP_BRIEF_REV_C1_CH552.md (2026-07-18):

# USB Replug Dongle Rev.C.1 CH552 Firmware Bring-up

Date: 2026-07-17  
Project: `D:\oh_my_usb`  
Target: cost-optimized Rev.C.1 production hardware

> This document supersedes `FIRMWARE_BRINGUP_BRIEF_REV_C.md`, which describes
> the older STM32F042 Rev.C board.

## 1. Deliverable

The production firmware project is:

```text
firmware/usb_replug_ch552/
```

It builds a CH552 binary exposing a USB CDC ACM control channel. The PC sees:

```text
CH334U USB 2.0 hub
├─ CH552 CDC control device (always connected)
└─ DUT port (FSUSB42 data disconnect + TPS2552 VBUS disconnect)
```

## 2. Safety invariants

Before USB initialization and after every reset:

```text
TARGET_PWR_EN_N = high  -> DUT VBUS off
TARGET_DATA_CMD = open-drain release -> FSUSB42 /OE high, D+/D- disconnected
HUB_RESET_N     = un-driven -> CH334U internal POR/pull-up; TP8 manual low reset
TARGET_FAULT_N  = input -> TPS2552 FAULT and CH552 P3.0 share the 5 V domain
```

CH552 P3.1 is physically unconnected. This removes the unsafe pre-firmware
5 V quasi-bidirectional pull-up path into the CH334U 3.3 V reset input.
The FSUSB42 `/OE` network uses equal 5.1k parts (R6/R8/R9), keeping `/OE` below
3.3 V even during CH552 POR while preserving a valid disconnected-state high.

Command order:

- `on`: connect data, wait 20 ms, enable VBUS, wait 100 ms, recheck fault.
- `off`: disconnect data, disable VBUS.
- `cycle`: off, wait 100–30000 ms, on.
- An active fault rejects `on`; a fault after enabling power forces safe-off.

## 3. USB interface

- USB 2.0 Full-Speed CDC ACM
- Device class/subclass/protocol: `02/00/00`
- EP0 control: 8 bytes
- EP1 interrupt IN: 8 bytes
- EP2 bulk OUT/IN: 64 bytes
- Stable serial: `RVC1-` plus ten uppercase hexadecimal chip-ID digits
- Engineering VID/PID: `1A86:5722`
- CH552 `VCC`: `VBUS_IN`, nominal 5 V; required for the selected 24 MHz clock

Windows can bind the inbox `usbser.sys` driver based on the compatible class
IDs. Linux and macOS use their normal CDC ACM drivers.

## 4. Command protocol

ASCII commands end in CR or LF. Responses end in CRLF.

```text
on
off
cycle
cycle 2000
on 1
off 1
cycle 1 2000
status
fault
version
help
```

Examples:

```text
OK
ERR invalid_command
ERR invalid_arg
ERR fault_active
STATE off fault=0 version=0.2.1-revc1
FAULT 0
VERSION 0.2.1-revc1
```

## 5. Build

```powershell
cd D:\oh_my_usb\firmware\usb_replug_ch552
py build.py clean
py build.py all
```

The build runs portable C unit tests before compiling with SDCC. The linked
image must remain below `0x3800`; the factory bootloader occupies the top 2 KiB.

## 6. Host CLI

```powershell
cd D:\oh_my_usb\host\usb-replug-cli
py -m pip install pyserial
py -m usb_replug ports
py -m usb_replug status
py -m usb_replug cycle --delay-ms 2000
```

The CLI automatically finds `1A86:5722`, supports `--serial` when several
dongles are attached, and accepts `--port` for explicit selection.

## 7. PCBA bring-up sequence

1. Inspect assembly polarity/orientation and shorts before connecting USB.
2. Verify `VBUS_IN`, `3V3`, and GND.
3. With blank MCU, verify DUT VBUS is off and FSUSB42 is disabled.
4. Program the firmware through J3 without overwriting the factory bootloader.
5. Verify CH334U hub enumeration.
6. Verify CH552 CDC enumeration and stable serial number.
7. Run `status`, `on`, `off`, and `cycle 2000`.
8. Measure TP5/TP6/TP7/TP8 and DUT VBUS against the command state.
9. Inject a current-limit fault and verify safe-off plus `ERR fault_active`.
10. Run 100 cycles against each representative DUT and collect OS logs.

## 8. Acceptance gates

Offline:

- command core unit tests pass
- descriptor tests pass
- host CLI tests pass
- SDCC build/link passes
- code and XRAM stay within enforced limits

On hardware:

- enumeration on Windows/Linux/macOS
- no 5 V drive into 3.3 V-only nets
- default safe-off at power-up/reset
- over-current safe-off
- 100-cycle reliability test
- no MCU/hub hang and no persistent OS USB errors

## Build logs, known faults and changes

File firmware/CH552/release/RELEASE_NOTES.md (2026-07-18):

# USB Replug Dongle Rev.C.1 Firmware 0.2.1

Release date: 2026-07-18  
Target MCU: WCH CH552T  
Target PCB: USB Replug Dongle Rev.C.1 with CH334U hub

## Release status

**Offline firmware release: PASS.** The former CH552 reset-state blocker is
removed in hardware: P3.1 is NC, CH334U RESET#/CDP is only connected to manual
TP8, and TPS2552 FAULT/P3.0 now share the 5 V domain. The equal 5.1 kΩ
R6/R8/R9 network keeps FSUSB42 `/OE` reset-safe.

Physical PCBA bring-up remains mandatory before product acceptance. It includes
rail measurements, hub/CDC enumeration, FSUSB42 and TPS2552 behavior, fault
injection, and 100-cycle representative-DUT testing.

## Behavior

- Safe boot: DUT VBUS off and D+/D- disconnected
- ON: connect data, wait 20 ms, enable VBUS, wait 100 ms, verify fault
- OFF: disconnect data, then disable VBUS
- Cycle range: 100–30000 ms; default 2000 ms
- Active-low over-current interlock with automatic safe-off
- CDC commands: `on`, `off`, `cycle`, `status`, `fault`, `version`, `help`
- Stable USB serial derived from the CH552 unique ID

## USB identity

Engineering default VID:PID is `1A86:5722`. Replace it with
manufacturer-owned or licensed identifiers before commercial distribution.

## Supersession

This release supersedes the blocked `0.2.0-revc1` archive. Do not flash the
older archive to production Rev.C.1 PCBAs.

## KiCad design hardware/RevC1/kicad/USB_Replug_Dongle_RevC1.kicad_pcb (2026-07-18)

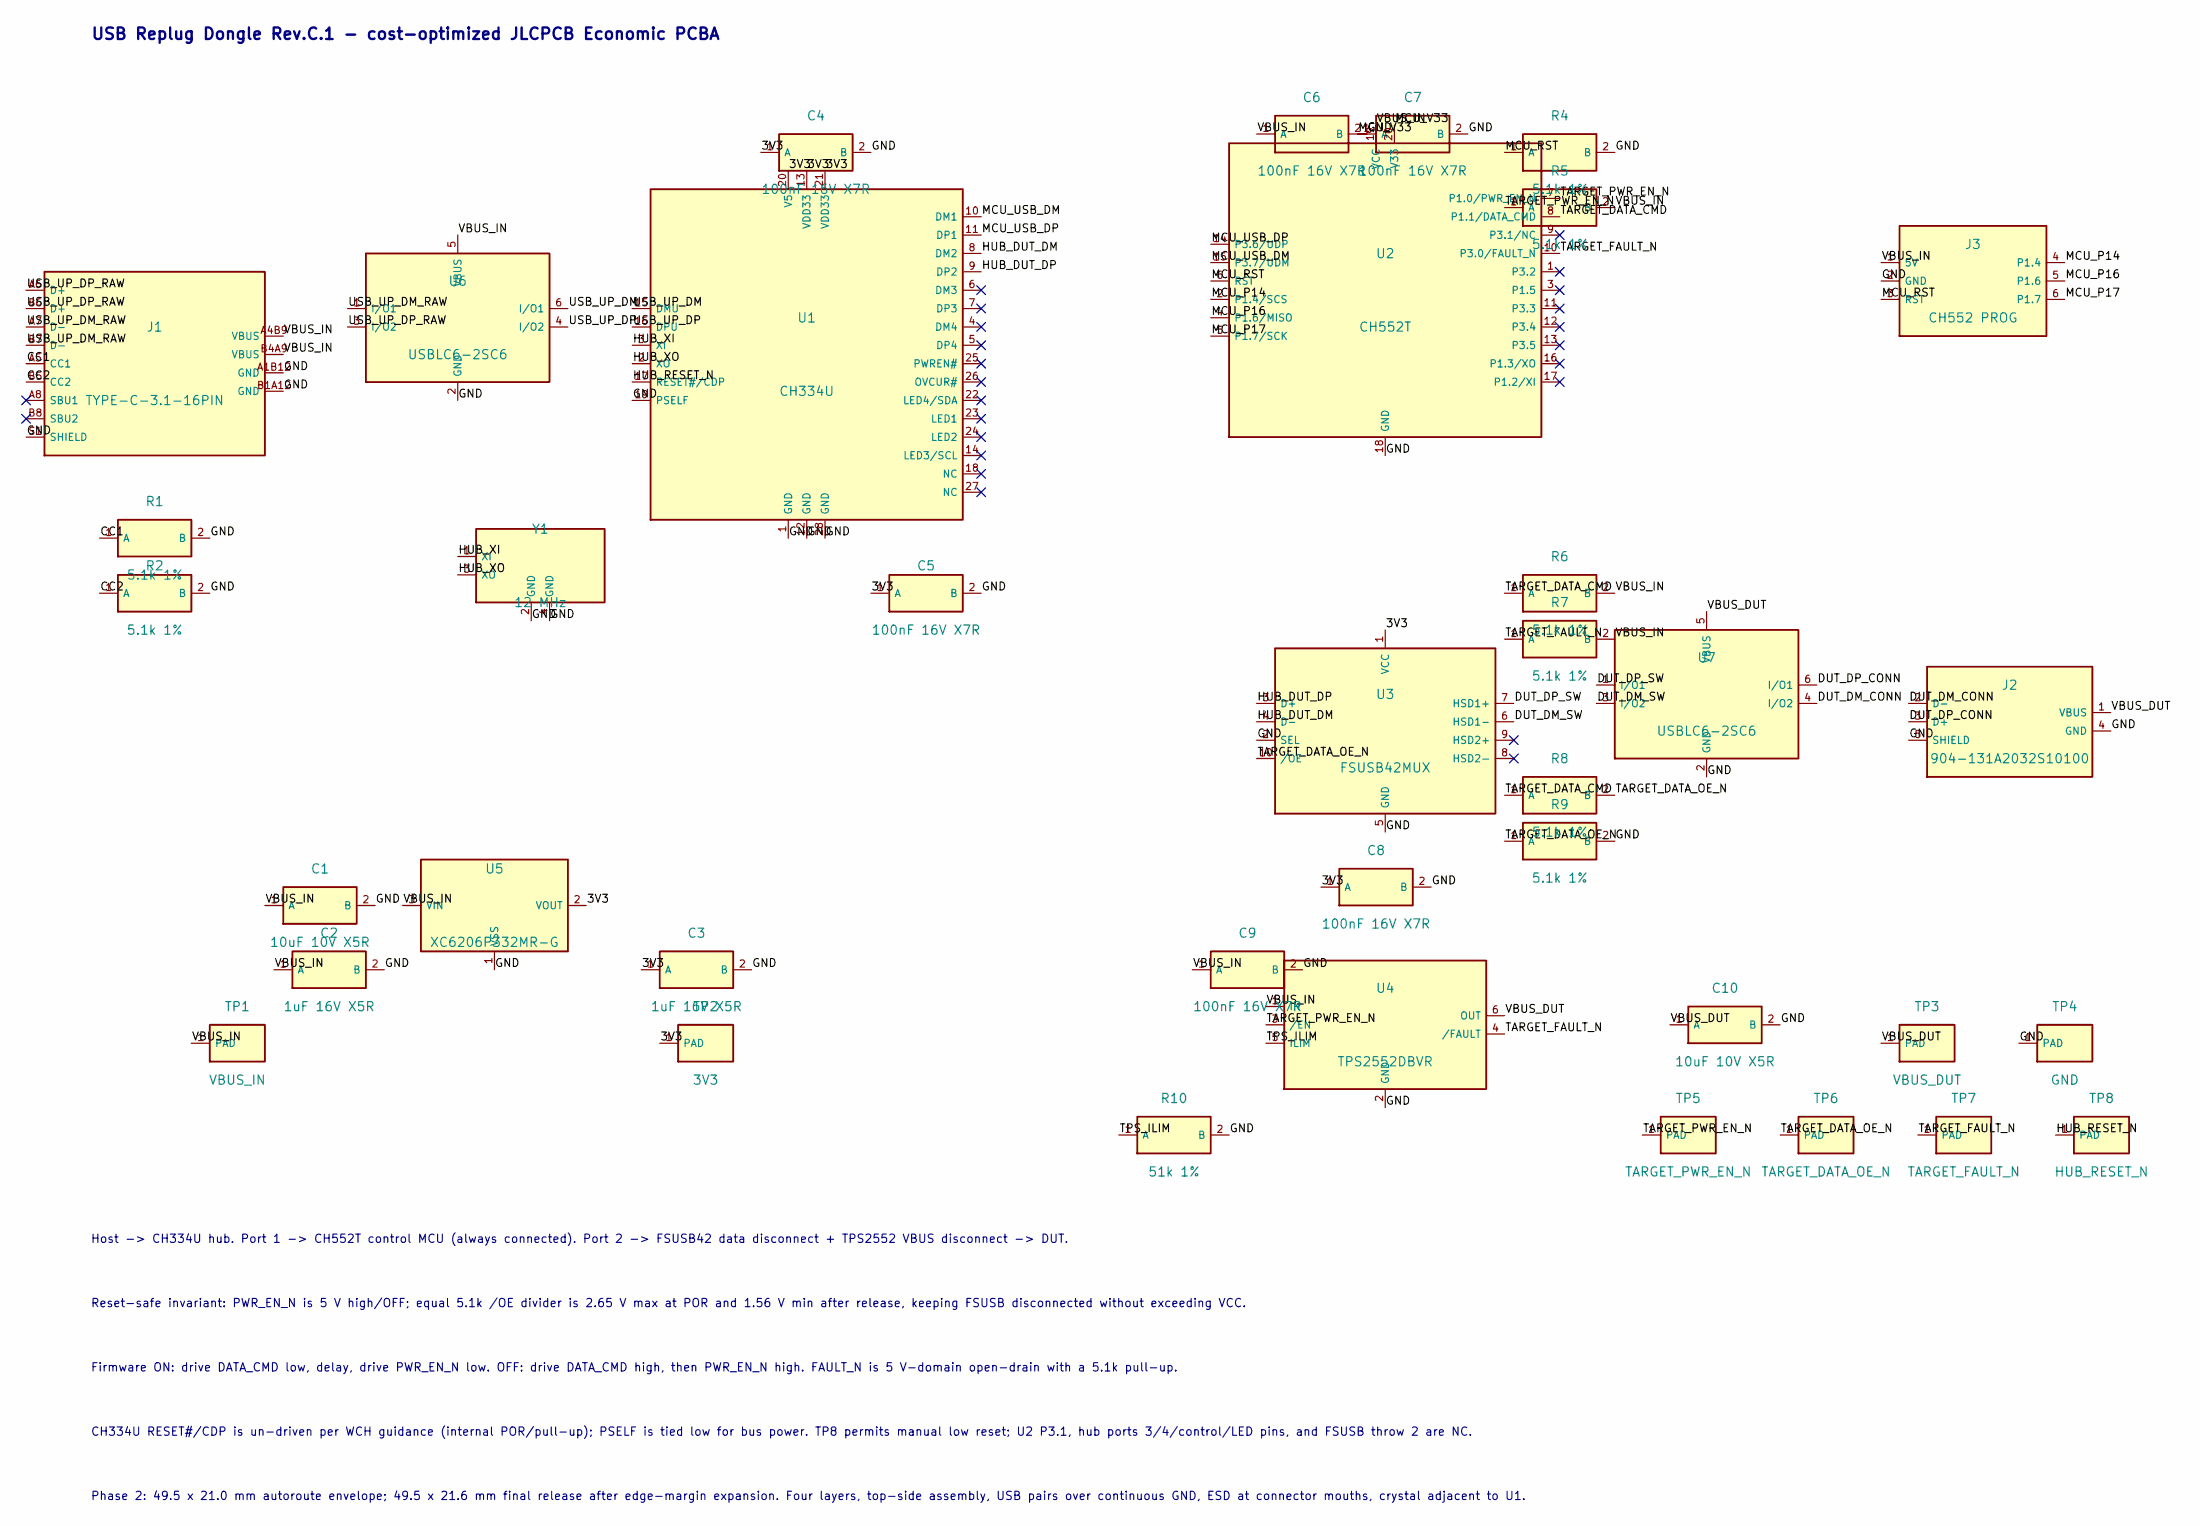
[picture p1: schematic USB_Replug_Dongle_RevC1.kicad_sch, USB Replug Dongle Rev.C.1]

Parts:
C1, C10: 10uF 10V X5R; C_0603_1608Metric; MPN 10uF 10V X5R; LCSC Part # C19702
C2, C3: 1uF 16V X5R; C_0603_1608Metric; MPN 1uF 16V X5R; LCSC Part # C15849
C4, C5, C6, C7, C8, C9: 100nF 16V X7R; C_0603_1608Metric; MPN 100nF 16V X7R; LCSC Part # C14663
J1: TYPE-C-3.1-16PIN; C7507405_USB_C; MPN TYPE-C-3.1-16PIN; LCSC Part # C7507405
J2: 904-131A2032S10100; C8328_USB_A; MPN 904-131A2032S10100; LCSC Part # C8328
J3: CH552 PROG; PROG_PADS_2x3_P1.27
R1, R2, R4, R5, R6, R7, R8, R9: 5.1k 1%; R_0603_1608Metric; MPN 5.1k 1%; LCSC Part # C23186
R10: 51k 1%; R_0603_1608Metric; MPN 51k 1%; LCSC Part # C107231
TP1: VBUS_IN; TP_Pad_0.7mm
TP2: 3V3; TP_Pad_0.7mm
TP3: VBUS_DUT; TP_Pad_0.7mm
TP4: GND; TP_Pad_0.7mm
TP5: TARGET_PWR_EN_N; TP_Pad_0.7mm
TP6: TARGET_DATA_OE_N; TP_Pad_0.7mm
TP7: TARGET_FAULT_N; TP_Pad_0.7mm
TP8: HUB_RESET_N; TP_Pad_0.7mm
U1: CH334U; QSOP-28_3.9x9.9mm_P0.635mm; MPN CH334U; LCSC Part # C5187524
U2: CH552T; TSSOP-20_4.4x6.5mm_P0.65mm; MPN CH552T; LCSC Part # C111367
U3: FSUSB42MUX; MSOP-10_3x3mm_P0.5mm; MPN FSUSB42MUX; LCSC Part # C11355
U4: TPS2552DBVR; SOT-23-6; MPN TPS2552DBVR; LCSC Part # C46506
U5: XC6206P332MR-G; SOT-23; MPN XC6206P332MR-G; LCSC Part # C5446
U6, U7: USBLC6-2SC6; SOT-23-6; MPN USBLC6-2SC6; LCSC Part # C7519
Y1: 12 MHz; Crystal_SMD_3225-4Pin_3.2x2.5mm; MPN X322512MSB4SI; LCSC Part # C9002

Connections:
/3V3: C3.1 (A), C4.1 (A), C5.1 (A), C8.1 (A), TP2.1, U1.13 (VDD33), U1.20 (V5), U1.21 (VDD33), U3.1 (VCC), U5.2 (VOUT)
/CC1: J1.A5 (CC1), R1.1 (A)
/CC2: J1.B5 (CC2), R2.1 (A)
/DUT_DM_CONN: J2.2 (D-), U7.4 (I/O2)
/DUT_DM_SW: U3.6 (HSD1-), U7.3 (I/O2)
/DUT_DP_CONN: J2.3 (D+), U7.6 (I/O1)
/DUT_DP_SW: U3.7 (HSD1+), U7.1 (I/O1)
/GND: C1.2 (B), C2.2 (B), C3.2 (B), C4.2 (B), C5.2 (B), C6.2 (B), C7.2 (B), C8.2 (B), C9.2 (B), C10.2 (B), J1.A1B12 (GND), J1.B1A12 (GND), J1.S1 (SHIELD), J2.4 (GND), J2.5 (SHIELD), J3.2 (GND), R1.2 (B), R2.2 (B), R4.2 (B), R9.2 (B), R10.2 (B), TP4.1, U1.1 (GND), U1.12 (GND), U1.19 (PSELF), U1.28 (GND), U2.18 (GND), U3.2 (SEL), U3.5 (GND), U4.2 (GND), U5.1 (VSS), U6.2 (GND), U7.2 (GND), Y1.2 (GND), Y1.4 (GND)
/HUB_DUT_DM: U1.8 (DM2), U3.4 (D-)
/HUB_DUT_DP: U1.9 (DP2), U3.3 (D+)
/HUB_RESET_N: TP8.1, U1.17 (RESET#/CDP)
/HUB_XI: U1.3 (XI), Y1.1 (XI)
/HUB_XO: U1.2 (XO), Y1.3 (XO)
/MCU_P14: J3.4 (P1.4), U2.2 (P1.4/SCS)
/MCU_P16: J3.5 (P1.6), U2.4 (P1.6/MISO)
/MCU_P17: J3.6 (P1.7), U2.5 (P1.7/SCK)
/MCU_RST: J3.3 (RST), R4.1 (A), U2.6 (RST)
/MCU_USB_DM: U1.10 (DM1), U2.15 (P3.7/UDM)
/MCU_USB_DP: U1.11 (DP1), U2.14 (P3.6/UDP)
/MCU_V33: C7.1 (A), U2.20 (V33)
/TARGET_DATA_CMD: R6.1 (A), R8.1 (A), U2.8 (P1.1/DATA_CMD)
/TARGET_DATA_OE_N: R8.2 (B), R9.1 (A), TP6.1, U3.10 (/OE)
/TARGET_FAULT_N: R7.1 (A), TP7.1, U2.10 (P3.0/FAULT_N), U4.4 (/FAULT)
/TARGET_PWR_EN_N: R5.1 (A), TP5.1, U2.7 (P1.0/PWR_EN_N), U4.3 (/EN)
/TPS_ILIM: R10.1 (A), U4.5 (ILIM)
/USB_UP_DM: U1.15 (DMU), U6.6 (I/O1)
/USB_UP_DM_RAW: J1.A7 (D-), J1.B7 (D-), U6.1 (I/O1)
/USB_UP_DP: U1.16 (DPU), U6.4 (I/O2)
/USB_UP_DP_RAW: J1.A6 (D+), J1.B6 (D+), U6.3 (I/O2)
/VBUS_DUT: C10.1 (A), J2.1 (VBUS), TP3.1, U4.6 (OUT), U7.5 (VBUS)
/VBUS_IN: C1.1 (A), C2.1 (A), C6.1 (A), C9.1 (A), J1.A4B9 (VBUS), J1.B4A9 (VBUS), J3.1 (5V), R5.2 (B), R6.2 (B), R7.2 (B), TP1.1, U2.19 (VCC), U4.1 (IN), U5.3 (VIN), U6.5 (VBUS)

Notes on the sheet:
USB Replug Dongle Rev.C.1 - cost-optimized JLCPCB Economic PCBA
Host -> CH334U hub. Port 1 -> CH552T control MCU (always connected). Port 2 -> FSUSB42 data disconnect + TPS2552 VBUS disconnect -> DUT.
Reset-safe invariant: PWR_EN_N is 5 V high/OFF; equal 5.1k /OE divider is 2.65 V max at POR and 1.56 V min after release, keeping FSUSB disconnected without exceeding VCC.
Firmware ON: drive DATA_CMD low, delay, drive PWR_EN_N low. OFF: drive DATA_CMD high, then PWR_EN_N high. FAULT_N is 5 V-domain open-drain with a 5.1k pull-up.
CH334U RESET#/CDP is un-driven per WCH guidance (internal POR/pull-up); PSELF is tied low for bus power. TP8 permits manual low reset; U2 P3.1, hub ports 3/4/control/LED pins, and FSUSB throw 2 are NC.
Phase 2: 49.5 x 21.0 mm autoroute envelope; 49.5 x 21.6 mm final release after edge-margin expansion. Four layers, top-side assembly, USB pairs over continuous GND, ESD at connector mouths, crystal adjacent to U1.

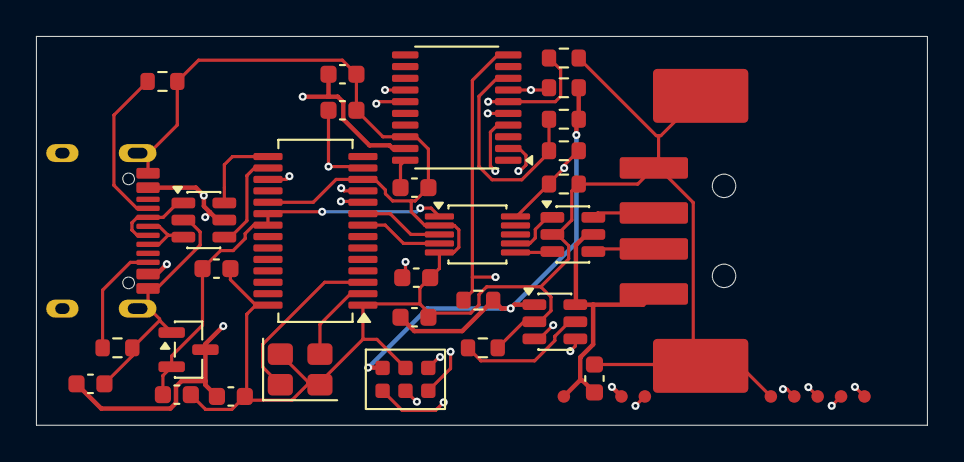
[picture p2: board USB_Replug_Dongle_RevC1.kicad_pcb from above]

Board: 4 copper layers, 49.5 x 21.6 mm, 38 parts (0 on the bottom side), 31 nets.

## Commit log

2026-07-18 Publish PortPulse Rev.C.1 hardware and host release
    Publish the validated USB replug hardware, firmware artifacts, manufacturing package, and native C host under the new PortPulse project identity. Keep the JLCPCB release traceable while leaving payme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
    Constraint: The repository was empty and the JLCPCB order-ready package had to remain reproducible and auditable.
    Rejected: Publishing legacy Rev.A/Rev.C outputs | They are superseded by the Rev.C.1 order-ready release.
    Confidence: high
    Scope-risk: moderate
    Directive: Re-run live JLCPCB stock and placement checks before any future order submission.
    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
    [USB_Replug_Dongle_RevC1.kicad_pcb, USB_Replug_Dongle_RevC1.kicad_sch, bom.csv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]
2026-07-18 Localize PortPulse README for Korean users
    Make the repository landing page explain the Rev.C.1 hardware, command interface, repository layout, validation boundary, and licensing in Korean.
    Constraint: Keep commands and paths copyable for Windows/Linux users.
    Rejected: Replacing technical identifiers with translated names | LCSC, KiCad, USB, and CLI identifiers must remain exact.
    Scope-risk: narrow
    Directive: Keep future CLI and hardware changes synchronized with the README examples.
    Tested: git diff --check.
    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
2026-07-18 Keep README focused on purpose and usage
    Make the Korean README explain only what PortPulse is and how to use it, with English retained as a supplementary translation.
    Constraint: The repository landing page should be immediately understandable to Korean users.
    Rejected: Keeping validation and repository inventory in README | Those details belong in the hardware and firmware release reports.
    Directive: Keep README examples synchronized with the native host CLI.
    Not-tested: No hardware or firmware behavior changed.
    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
2026-07-18 Start README directly with the product description
    Remove the unnecessary language notice so the Korean README opens directly with PortPulse purpose and usage.
    Constraint: Korean is the primary repository documentation.
    Rejected: Keeping a language banner | The separate English file is discoverable through the repository without interrupting the primary README.
    Directive: Keep the primary README concise and Korean-first.
    Not-tested: No runtime behavior changed.
    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
